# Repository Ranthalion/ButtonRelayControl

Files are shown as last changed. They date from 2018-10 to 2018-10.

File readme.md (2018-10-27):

# Button Relay Control

Controls 2 relays based on liquid level sensors and push buttons

Video demo and more images at https://imgur.com/a/c6JBYJK

Schematic

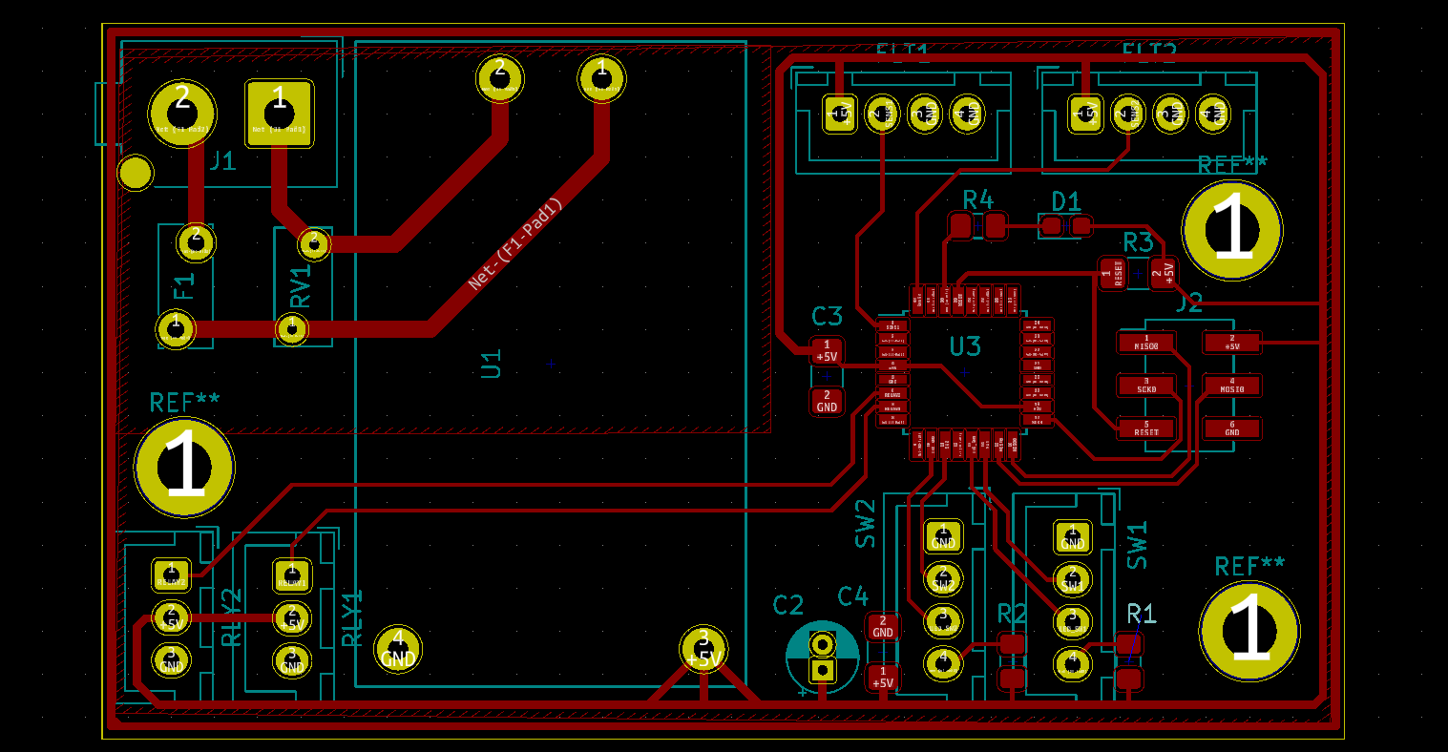
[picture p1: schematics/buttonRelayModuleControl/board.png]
Schematic


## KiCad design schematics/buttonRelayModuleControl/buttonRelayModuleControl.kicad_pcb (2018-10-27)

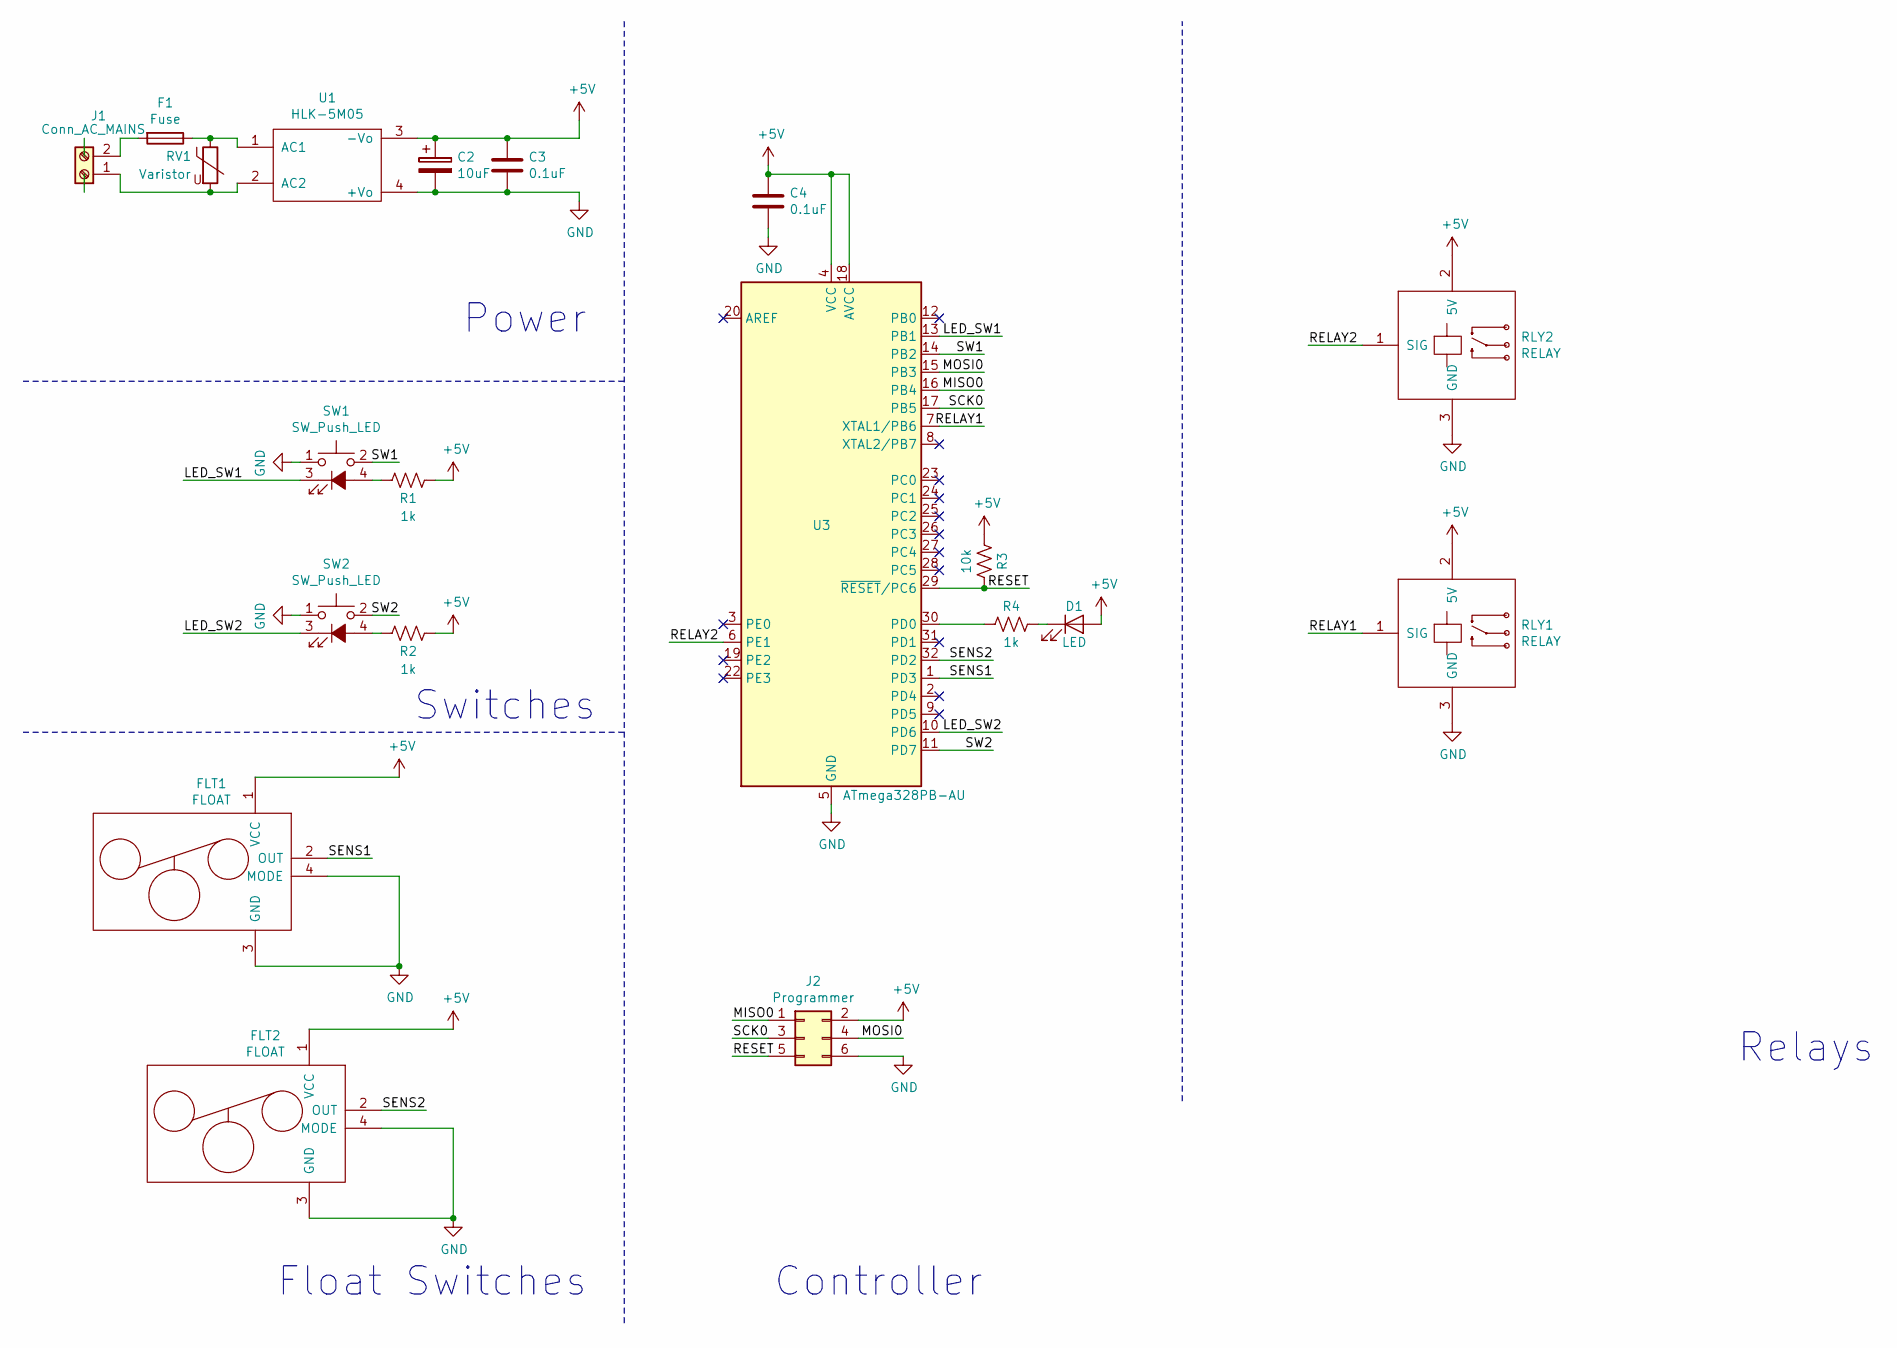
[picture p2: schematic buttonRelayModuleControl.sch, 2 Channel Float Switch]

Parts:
C2: 10uF; CP_Radial_D4.0mm_P1.50mm
C3, C4: 0.1uF; C_1206_3216Metric_Pad1.42x1.75mm_HandSolder
D1: LED; LED_0603_1608Metric_Pad1.05x0.95mm_HandSolder
F1: Fuse; Fuse_Bourns_MF-RG300; Part No 0466.125NR
FLT1, FLT2: FLOAT; JST_XH_B04B-XH-A_1x04_P2.50mm_Vertical
J1: Conn_AC_MAINS; Molex_Mega-Fit_76829-0102_2x01_P5.70mm_Vertical
J2: Programmer; PinHeader_2x03_P2.54mm_Vertical_SMD
R1, R2, R4: 1k; R_0805_2012Metric_Pad1.15x1.40mm_HandSolder
R3: 10k; R_1206_3216Metric_Pad1.42x1.75mm_HandSolder
RLY1, RLY2: RELAY; JST_XH_B03B-XH-A_1x03_P2.50mm_Vertical
RV1: Varistor; RV_Disc_D7mm_W3.4mm_P5mm; Part No ERZ-V14D241
SW1, SW2: SW_Push_LED; JST_XH_B04B-XH-A_1x04_P2.50mm_Vertical
U1: HLK-5M05
U3: ATmega328PB-AU; TQFP-32_7x7mm_P0.8mm

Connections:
+5V: C2.1, C3.1, C4.1, D1.2 (A), FLT1.1 (VCC), FLT2.1 (VCC), J2.2, R1.1, R2.1, R3.2, RLY1.2 (5V), RLY2.2 (5V), U1.3 (-Vo), U3.4 (VCC), U3.18 (AVCC)
/LED_SW1: SW1.3 (K), U3.13 (PB1)
/LED_SW2: SW2.3 (K), U3.10 (PD6)
/MISO0: J2.1, U3.16 (PB4)
/MOSI0: J2.4, U3.15 (PB3)
/RELAY1: RLY1.1 (SIG), U3.7 (XTAL1/PB6)
/RELAY2: RLY2.1 (SIG), U3.6 (PE1)
/RESET: J2.5, R3.1, U3.29 (~RESET~/PC6)
/SCK0: J2.3, U3.17 (PB5)
/SENS1: FLT1.2 (OUT), U3.1 (PD3)
/SENS2: FLT2.2 (OUT), U3.32 (PD2)
/SW1: SW1.2, U3.14 (PB2)
/SW2: SW2.2, U3.11 (PD7)
GND: C2.2, C3.2, C4.2, FLT1.3 (GND), FLT1.4 (MODE), FLT2.3 (GND), FLT2.4 (MODE), J2.6, RLY1.3 (GND), RLY2.3 (GND), SW1.1, SW2.1, U1.4 (+Vo), U3.5 (GND), U3.21 (GND)
unnamed: D1.1 (K), R4.1
unnamed: F1.1, RV1.1, U1.1 (AC1)
unnamed: F1.2, J1.2
unnamed: J1.1, RV1.2, U1.2 (AC2)
unnamed: R1.2, SW1.4 (A)
unnamed: R2.2, SW2.4 (A)
unnamed: R4.2, U3.30 (PD0)

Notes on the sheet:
Power
Switches
Float Switches
Relays
Controller

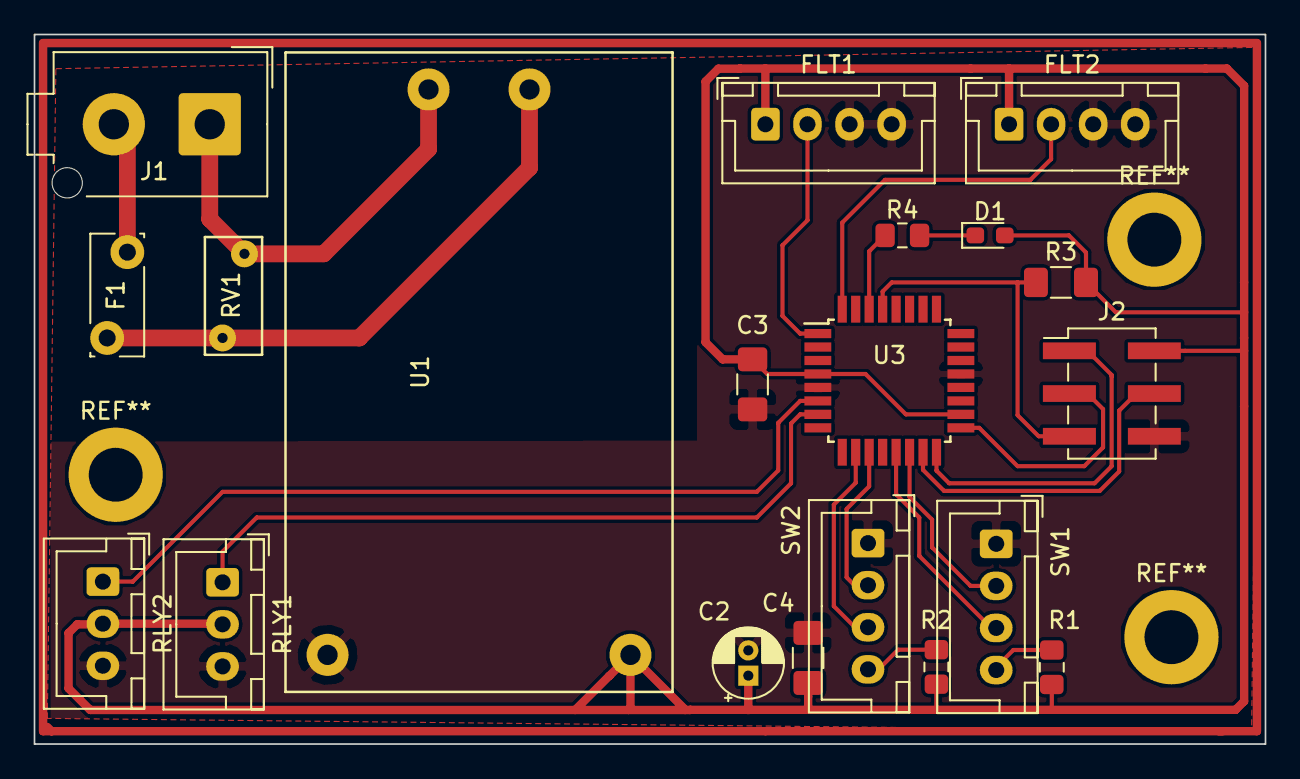
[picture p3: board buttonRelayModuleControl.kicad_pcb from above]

Board: 2 copper layers, 73.2 x 42.2 mm, 20 parts (0 on the bottom side), 21 nets.

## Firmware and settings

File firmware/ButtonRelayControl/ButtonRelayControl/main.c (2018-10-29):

#include <atmel_start.h>
#include <program.h>
#include <timeout.h>
#include <button.h>
#include <util/delay.h>
#include <avr/sleep.h>

#define BUTTON_RATE 90
#define SLEEP_THRESHOLD 500

static absolutetime_t led_off();
void startupAnimation();
void handleRunningState();
void handleIdleState();
void handleChannel1State();
void handleChannel2State();

volatile int x = 0;
volatile uint32_t idleCounter = 0;

button_struct_t sw1;
button_struct_t sw2;

timer_struct_t led_timer = {led_off, NULL};

static absolutetime_t led_cb()
{
	x++;
	if (x == 500)
		LED_set_level(0);
	else if (x == 1000)
		LED_set_level(1);
		
	if (x > 1000)
		x=0;
		
	return 8; 
}


static absolutetime_t button_cb()
{
	ReadButton(&sw1);
	ReadButton(&sw2);
	idleCounter++;
	return BUTTON_RATE;
}

static absolutetime_t led_off()
{
	LED_set_level(true);
	return 0;
}

void LED_flash()
{
	LED_set_level(false);
	TIMER_0_timeout_create(&led_timer, 10);
}

enum System_State { System_Power_On, System_Idle, System_Running, System_Error, Test};
enum Channel_State {Idle, Button_Down, Button_Held, Short_Press, Long_Press, Static_On, Monitor_On, Stop};

enum System_State system_state = System_Power_On;
enum Channel_State channel1_state = Idle;
enum Channel_State channel2_state = Idle;

int main(void)
{
	/* Initializes MCU, drivers and middleware */
	atmel_start_init();

	timer_struct_t led_timer = {led_cb, NULL};

	SW1_LED_Off();
	SW2_LED_Off();

	InitializeButton(&sw1, &PINB, PINB2);
	InitializeButton(&sw2, &PIND, PIND7);
	
	ENABLE_INTERRUPTS();

	timer_struct_t button_timer = {button_cb, NULL};
	TIMER_0_timeout_create(&button_timer, BUTTON_RATE);

	while (1) {
		switch(system_state) {
			case System_Power_On:
				startupAnimation();
				system_state = System_Running;
				//system_state = Test;
			break;
			
			case System_Running:
				handleRunningState();
				if (channel1_state == Idle && channel2_state == Idle)
				{
					if (idleCounter > SLEEP_THRESHOLD)
					{
						system_state = System_Idle;	
					}					
				}
				else
				{
					idleCounter = 0;
				}
				break;
			
			case System_Idle:
				handleIdleState();
				idleCounter = 0;
				system_state = System_Running;
				break;
				
			default:
				system_state = System_Power_On;
				break;
		}
	}
}

void startupAnimation()
{
	for(int i = 0; i < 5; i++)
	{
		LED_toggle_level();
		_delay_ms(50);
		LED_toggle_level();
		_delay_ms(50);
	}
	SW1_LED_flash();
	SW2_LED_flash();
}

void handleRunningState()
{
	TIMER_0_timeout_call_next_callback();
	handleChannel1State();
	handleChannel2State();
}

void handleIdleState()
{
		_delay_ms(1);
		set_sleep_mode(SLEEP_MODE_PWR_DOWN);
		DISABLE_INTERRUPTS();
		sleep_enable();
		ENABLE_INTERRUPTS();
		sleep_cpu();
		sleep_disable();
		idleCounter = 0;		
}

void handleChannel1State()
{
	switch(channel1_state) {
		case Idle:
			if (sw1.buttonDown == true)
			{
				sw1.buttonDown = false;
				channel1_state = Button_Down;				
			}			
			break;
			
		case Button_Down:		
			SW1_LED_flash();
			channel1_state = Button_Held;
			break;
			
		case Button_Held:
			if (sw1.buttonUp == true)
			{
				sw1.buttonUp = false;
				if (sw1.duration > BUTTON_HOLD_THRESHOLD )
				{
					channel1_state = Long_Press;					
				}
				else
				{
					channel1_state = Short_Press;					
				}
			}
			break;
			
		case Short_Press: 
			SW1_LED_On();
			RELAY1_set_level(true);
			channel1_state = Static_On;
			break;
			
		case Long_Press: 
			if(SENS1_get_level() == false)
			{
				channel1_state = Stop;
			}
			else
			{
				SW1_LED_Pulse();
				RELAY1_set_level(true);
				channel1_state = Monitor_On;
			}
			break;
		
		case Static_On:
			if (sw1.buttonUp == true)
			{
				sw1.buttonUp = false;
				channel1_state = Stop;
			}
			break;
		
		case Monitor_On:
			if (sw1.buttonUp == true)
			{
				sw1.buttonUp = false;
				channel1_state = Stop;
			}
			if(SENS1_get_level() == false)
			{
				channel1_state = Stop;
			}
			break;
		
		case Stop: 
			RELAY1_set_level(false);
			SW1_LED_Off();
			channel1_state = Idle;
			break;
			
		default:
			
			break;
	}	
}

void handleChannel2State()
{
	
	switch(channel2_state) {
		case Idle:
			if (sw2.buttonDown == true)
			{
				sw2.buttonDown = false;
				channel2_state = Button_Down;
			}
			break;
		
		case Button_Down:
			SW2_LED_flash();
			channel2_state = Button_Held;
			break;
		
		case Button_Held:
			if (sw2.buttonUp == true)
			{
				sw2.buttonUp = false;
				if (sw2.duration > BUTTON_HOLD_THRESHOLD )
				{
					channel2_state = Long_Press;
				}
				else
				{
					channel2_state = Short_Press;
				}
			}
			break;
		
		case Short_Press:
			SW2_LED_On();
			RELAY2_set_level(true);
			channel2_state = Static_On;
			break;
		
		case Long_Press:
			if(SENS2_get_level() == false)
			{
				channel2_state = Stop;
			}
			else
			{
				SW2_LED_Pulse();
				RELAY2_set_level(true);
				channel2_state = Monitor_On;
			}
			break;
		
		case Static_On:
			if (sw2.buttonUp == true)
			{
				sw2.buttonUp = false;
				channel2_state = Stop;
			}
			break;
		
		case Monitor_On:
			if (sw2.buttonUp == true)
			{
				sw2.buttonUp = false;
				channel2_state = Stop;
			}
			if(SENS2_get_level() == false)
			{
				channel2_state = Stop;
			}
			break;
		
		case Stop:
			RELAY2_set_level(false);
			SW2_LED_Off();
			channel2_state = Idle;
			break;
		
		default:
			break;
	}
}

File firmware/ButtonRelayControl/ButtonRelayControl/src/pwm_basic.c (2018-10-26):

/**
 * \file
 *
 * \brief PWM Basic driver implementation.
 *
 (c) 2018 Microchip Technology Inc. and its subsidiaries.

    Subject to your compliance with these terms,you may use this software and
    any derivatives exclusively with Microchip products.It is your responsibility
    to comply with third party license terms applicable to your use of third party
    software (including open source software) that may accompany Microchip software.

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
    IN NO EVENT WILL MICROCHIP BE LIABLE FOR ANY INDIRECT, SPECIAL, PUNITIVE,
    INCIDENTAL OR CONSEQUENTIAL LOSS, DAMAGE, COST OR EXPENSE OF ANY KIND
    WHATSOEVER RELATED TO THE SOFTWARE, HOWEVER CAUSED, EVEN IF MICROCHIP HAS
    BEEN ADVISED OF THE POSSIBILITY OR THE DAMAGES ARE FORESEEABLE. TO THE
    FULLEST EXTENT ALLOWED BY LAW, MICROCHIP'S TOTAL LIABILITY ON ALL CLAIMS IN
    ANY WAY RELATED TO THIS SOFTWARE WILL NOT EXCEED THE AMOUNT OF FEES, IF ANY,
    THAT YOU HAVE PAID DIRECTLY TO MICROCHIP FOR THIS SOFTWARE.
 *
 */

/**
 * \defgroup doc_driver_pwm_basic PWM Basic Driver
 * \ingroup doc_driver_pwm
 *
 * \section doc_driver_pwm_normal_rev Revision History
 * - v0.0.0.1 Initial Commit
 *
 *@{
 */
#include <pwm_basic.h>

/**
 * \brief Initialize PWM
 * If module is configured to disabled state, the clock to the PWM is disabled
 * if this is supported by the device's clock system.
 *
 * \return Initialization status.
 */
int8_t LED_SW2_init()
{

	/* Enable TC0 */
	PRR0 &= ~(1 << PRTIM0);

	TCCR0A = (1 << COM0A1) | (1 << COM0A0)   /* Set OCA on Compare Match, clear OCA on BOTTOM (inverting mode) */
	         | (0 << COM0B1) | (0 << COM0B0) /* Normal port operation, OCB disconnected */
	         | (1 << WGM01) | (1 << WGM00);  /* TC8 Mode 3 Fast PWM */

	TCCR0B = 0                                          /* TC8 Mode 3 Fast PWM */
	         | (0 << CS02) | (1 << CS01) | (1 << CS00); /* IO clock divided by 64 */

	// TIMSK0 = 0 << OCIE0B /* Output Compare B Match Interrupt Enable: disabled */
	//		 | 0 << OCIE0A /* Output Compare A Match Interrupt Enable: disabled */
	//		 | 0 << TOIE0; /* Overflow Interrupt Enable: disabled */

	OCR0A = 0x98; /* Output compare A: 0x98 */

	// OCR0B = 0x0; /* Output compare B: 0x0 */

	return 0;
}

/**
 * \brief Enable PWM output on channel 0
 *
 * \return Nothing
 */
void LED_SW2_enable_output_ch0()
{

	TCCR0A |= ((1 << COM0A1) | (1 << COM0A0));
}

/**
 * \brief Disable PWM output on channel 0
 *
 * \return Nothing
 */
void LED_SW2_disable_output_ch0()
{

	TCCR0A &= ~((1 << COM0A1) | (1 << COM0A0));
}

/**
 * \brief Load COUNTER register in LED_SW2
 *
 * \param[in] counter_value The value to load into COUNTER
 *
 * \return Nothing
 */
void LED_SW2_load_counter(LED_SW2_register_t counter_value)
{
	TCNT0 = counter_value;
}

/**
 * \brief Load duty cycle register in for channel 0.
 * The physical register may have different names, depending on the hardware.
 * This is not the duty cycle as percentage of the whole period, but the actual
 * counter compare value.
 *
 * \param[in] counter_value The value to load into the duty cycle register.
 *
 * \return Nothing
 */
void LED_SW2_load_duty_cycle_ch0(LED_SW2_register_t duty_value)
{
	OCR0A = duty_value;
}


/**
 * \brief Initialize PWM
 * If module is configured to disabled state, the clock to the PWM is disabled
 * if this is supported by the device's clock system.
 *
 * \return Initialization status.
 */
int8_t LED_SW1_init()
{

	/* Enable TC1 */
	PRR0 &= ~(1 << PRTIM1);

	TCCR1A = (1 << COM1A1) | (1 << COM1A0)   /* Set OCA on Compare Match, clear OCA on BOTTOM (inverting mode) */
	         | (0 << COM1B1) | (0 << COM1B0) /* Normal port operation, OCB disconnected */
	         | (0 << WGM11) | (1 << WGM10);  /* TC16 Mode 5 Fast 8-bit PWM */

	TCCR1B = (0 << WGM13) | (1 << WGM12)                /* TC16 Mode 5 Fast 8-bit PWM */
	         | 0 << ICNC1                               /* Input Capture Noise Canceler: disabled */
	         | 0 << ICES1                               /* Input Capture Edge Select: disabled */
	         | (0 << CS12) | (1 << CS11) | (1 << CS10); /* IO clock divided by 64 */

	// ICR1 = 0x0; /* Input capture value: 0x0 */

	OCR1A = 0x96; /* Output compare A: 0x96 */

	// OCR1B = 0x0; /* Output compare B: 0x0 */

	// TIMSK1 = 0 << OCIE1B /* Output Compare B Match Interrupt Enable: disabled */
	//		 | 0 << OCIE1A /* Output Compare A Match Interrupt Enable: disabled */
	//		 | 0 << ICIE1 /* Input Capture Interrupt Enable: disabled */
	//		 | 0 << TOIE1; /* Overflow Interrupt Enable: disabled */

	return 0;
}

/**
 * \brief Enable PWM output on channel 0
 *
 * \return Nothing
 */
void LED_SW1_enable_output_ch0()
{

	TCCR1A |= ((1 << COM1A1) | (1 << COM1A0));
}

/**
 * \brief Disable PWM output on channel 0
 *
 * \return Nothing
 */
void LED_SW1_disable_output_ch0()
{
	TCCR1A &= ~((1 << COM1A1) | (1 << COM1A0));
}


/**
 * \brief Load COUNTER register in LED_SW1
 *
 * \param[in] counter_value The value to load into COUNTER
 *
 * \return Nothing
 */
void LED_SW1_load_counter(LED_SW1_register_t counter_value)
{
	TCNT1 = counter_value;
}

/**
 * \brief Load duty cycle register in for channel 0.
 * The physical register may have different names, depending on the hardware.
 * This is not the duty cycle as percentage of the whole period, but the actual
 * counter compare value.
 *
 * \param[in] counter_value The value to load into the duty cycle register.
 *
 * \return Nothing
 */
void LED_SW1_load_duty_cycle_ch0(LED_SW1_register_t duty_value)
{
	OCR1A = duty_value;
}

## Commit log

2018-10-21 Schematic and board layout
    [buttonRelayControl.kicad_pcb, buttonRelayControl.sch, buttonRelayModuleControl.kicad_pcb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]
2018-10-22 Initial Firmware
    [buttonRelayModuleControl.kicad_pcb, buttonRelayModuleControl.sch]
2018-10-23 Enable pin change interrupts
2018-10-23 Timer setup
2018-10-24 LED Animation
2018-10-24 Add board layout image
    [buttonRelayModuleControl.kicad_pcb]
2018-10-26 Button interrupts and button LED flash
2018-10-26 Implement state machines and activate relays
2018-10-26 Add level sensor to complete core functionality
2018-10-27 Add logo to board
    [buttonRelayModuleControl.kicad_pcb]
